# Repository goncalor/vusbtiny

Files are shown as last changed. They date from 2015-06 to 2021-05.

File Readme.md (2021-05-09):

# Introduction

VUSBtiny is a small in-system programmer (ISP) for Atmel AVR microcontrollers. It allows you to program microcontrollers on the go, without carrying a big programmer with you.

VUSBtiny is based on the [USBtinyISP](https://learn.adafruit.com/usbtinyisp). It uses an Atmel AVR microcontroller running [V-USB](https://www.obdev.at/products/vusb/index.html), which allows it to communicate with your computer via a USB port.

The programmer was not developed by me, but with this repository I added to it in some ways:

- edited the code so that it compiles with the most recent versions of `avr-gcc`
- designed a PCB for the project, in a way which should make it simple to be hand produced
- wrote this readme, which can help you make your own VUSBtiny.

You can find the original VUSBtiny page [here](https://web.archive.org/web/20180423215321/http://www.simpleavr.com/avr/vusbtiny) (or [here](https://simpleavr.github.io/old_projects/avr_vusbtiny/index.html)).

# License

VUSBtiny is licensed under [GNU GPL v2.0](http://choosealicense.com/licenses/gpl-2.0/). The license is in the file `LICENSE.txt`. The changes I made are released under the same license.

The V-USB driver is licensed under GNU GPL v2.0. If you intend to use V-USB commercially read [this page](https://www.obdev.at/products/vusb/license.html).

# Needed components

To assemble your own VUSBtiny you will need the following components:

- an Atmel AVR microcontroller [compatible with V-USB](https://www.obdev.at/products/vusb/index.html). I suggest ATtiny45 or ATtiny85
- one USB port (male and type A)
- two 68 Ω resistors
- one 1.5 kΩ resistor
- two 3.6 V Zener diodes
- a 10 μF capacitor (optional but recommended)
- a breadboard, perfboard or PCB to assemble the circuit.

# How to flash the AVR

The following instructions teach you how you can flash the Atmel AVR you chose to be the brain of your VUSBtiny. I will assume you are using ATtiny45 or ATtiny85. The instructions should be very similar even if you are using others.

## With an Arduino Uno

1. Choose a microcontroller compatible with V-USB. You can read about the required specs [here](https://www.obdev.at/products/vusb/). You need at least a 2 kB flash and 128 B of RAM. If you don't want to use an external oscillator your microcontroller must have a 16.5 MHz internal RC oscillator.
1. [Setup your Arduino as an ATtiny programmer](http://highlowtech.org/?p=1695)
1. Program Arduino Uno with the "ArduinoISP" sketch. This step is done without the capacitor between the RESET and GND pins of the Arduino. After you upload the "ArduinoISP" sketch connect the capacitor, as described in the link above
1. Adjust the following options in the `makefile`:
    - `MCU=attiny85`, for example
    - possibly adjust `PROGRAMMER_MCU` also. For ATtiny85/45 this is not needed
    - `AVRDUDE_PROGRAMMERID=avrisp`
    - `AVRDUDE_PORT=/dev/ttyACM0` or to whatever port the Arduino Uno is connected to. You check which port to use by running `dmesg` right after you connect your Arduino. The last lines in the output should mention some `tty` port
    - `BAUD=19200`. This value must match the one in the `Serial.begin()` in the "ArduinoISP" example
    - change the fuses if needed (`FUSE_L` and `FUSE_H`)
1. Do `make`. The source should compile successfully
1. Do `make install`
1. Set the fuses (if needed). On ATtiny85/45 we need to disable the reset pin which will be used as a normal I/O pin, which means you will not be able to program this microcontroller anymore using the Arduino Uno. If you need to reverse this step you need a HVSP (High Voltage Serial Programmer).
    - the fuses differ from device to device. The `makefile` is prepared for ATtiny85/45. If you have another MCU search for a fuse calculator that can aid you setting the correct fuses
    - when you're ready run `make fuse`

# How to use your new programmer

Your newly made programmer will be seen as a USBtinyISP programmer. That means the options you give to `avrdude` will be the same as if you had a true USBtinyISP connected. Example (flashing a simple blink code):

	avrdude -c usbtiny -p t85 -U flash:w:blinkC.hex

You may have to run with `sudo`, or set correct options in your system.

# Troubleshooting

1. Checking if your device was recognised

	Little after you connect the VUSBtiny to your computer if you run `dmesg` you should see something like this:

		[27548.612082] usb 4-1.5: new low-speed USB device number 105 using ehci-pci
		[27548.639576] usb 4-1.5: New USB device found, idVendor=1781, idProduct=0c9f
		[27548.639587] usb 4-1.5: New USB device strings: Mfr=0, Product=2, SerialNumber=0
		[27548.639592] usb 4-1.5: Product: USBtinyISP

	If instead you see only error messages this means the VUSBtiny was not correctly recognised, so it will not work. Try reconnecting.

2. When programming with VUSBtiny `avrdude` throws `Operation not permitted` error

		avrdude -c usbtiny -p t85 -U flash:w:blinkC.hex
	
		avrdude: error: usbtiny_transmit: error sending control message: Operation not permitted
		avrdude: initialization failed, rc=-1
		         Double check connections and try again, or use -F to override
		         this check.
	
		avrdude: error: usbtiny_transmit: error sending control message: Operation not permitted
		avrdude done.  Thank you.

	If you see `avrdude` throwing the previous error back atcha it is probably a permissions problem and you have two options:

	- run the command with `sudo` or
	- [write a udev rule](https://mightyohm.com/blog/2010/03/run-avrdude-without-root-privs-in-ubuntu/)

3. When programming with VUSBtiny `avrdude` throws `initialization failed, rc=-1` error

		avrdude -c usbtiny -p t85 -U flash:w:blinkC.hex 

		avrdude: initialization failed, rc=-1
			 Double check connections and try again, or use -F to override
			 this check.

		avrdude done.  Thank you.

	If you see this error you probably made a mistake when hooking up the programmer (VUSBtiny) to the target (whatever microcontroller you are programming). Recheck your connections against a 6-pin ISP header pinout and the MISO, MOSI, SCK, RST, VCC and GND pins of your microcontroller.

# Improvements

Some improvements that should be made to the PCB are:

- leave more space between the capacitor and the ISP headers. This way the capacitor can be bent to be made horizontal without difficulting access to the ISP header pins

- increase spacing between traces. This is meant to ease manual production and soldering of the board

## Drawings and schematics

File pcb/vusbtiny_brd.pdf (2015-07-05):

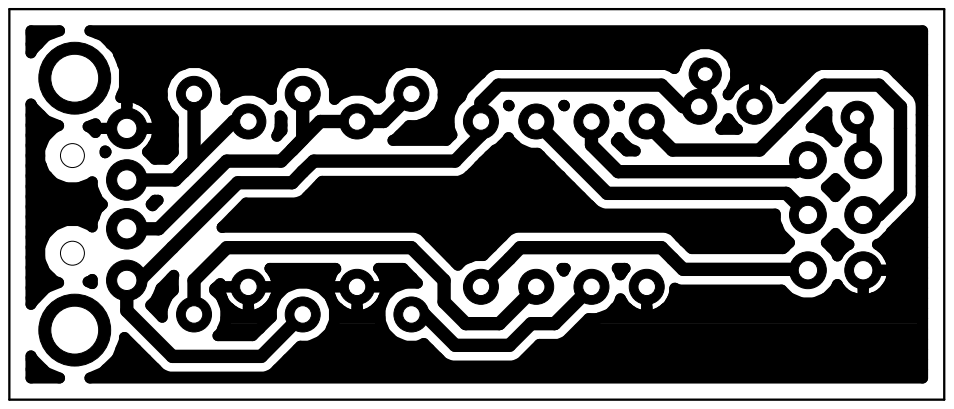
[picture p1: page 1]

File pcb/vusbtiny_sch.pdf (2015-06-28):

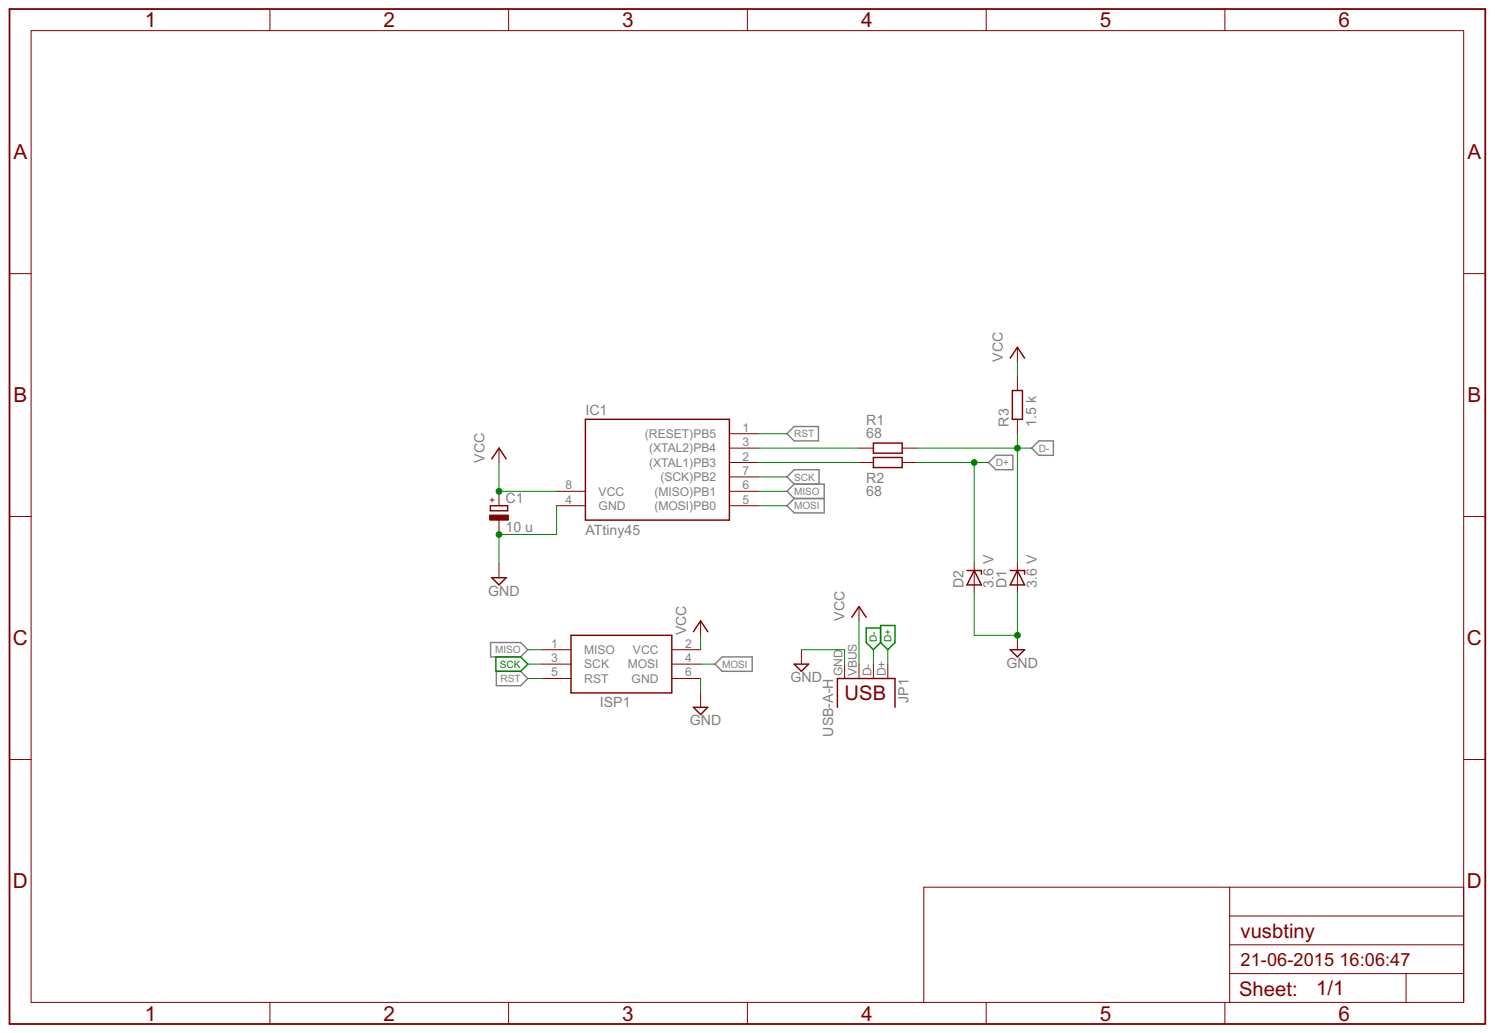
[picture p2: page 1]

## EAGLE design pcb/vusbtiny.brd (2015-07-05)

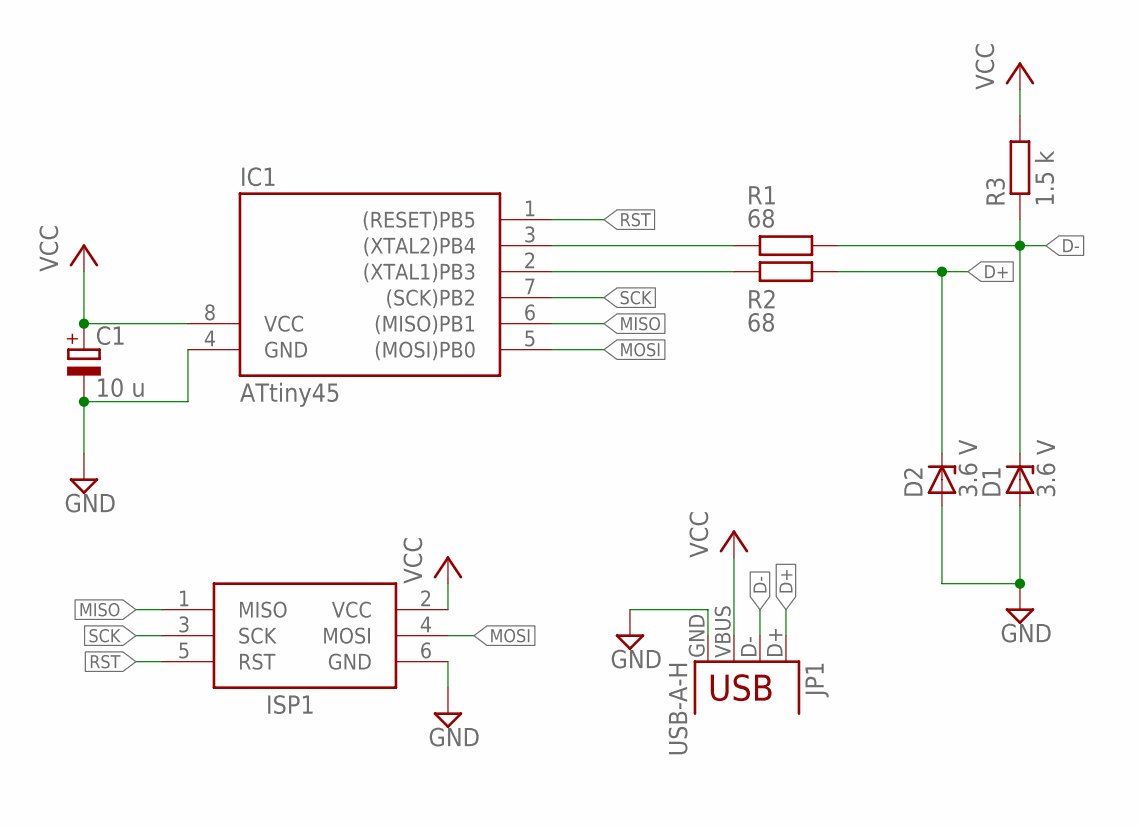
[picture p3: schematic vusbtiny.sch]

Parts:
C1: 10 u; E2,5-5
D1, D2: 3.6 V; DO34Z7
IC1: ATtiny45; DIL08
ISP1: AVRISP-6; AVRISP
JP1: USB-A-H
R1, R2: 68; 0207/10
R3: 1.5 k; 0207/10

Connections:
D+: D2.C, JP1.D+, R2.2
D-: D1.C, JP1.D-, R1.2, R3.1
GND: C1.-, D1.A, D2.A, IC1.4 (GND), ISP1.6 (GND), JP1.GND
MISO: IC1.6 ((MISO)PB1), ISP1.1 (MISO)
MOSI: IC1.5 ((MOSI)PB0), ISP1.4 (MOSI)
unnamed: IC1.3 ((XTAL2)PB4), R1.1
unnamed: IC1.2 ((XTAL1)PB3), R2.1
RST: IC1.1 ((RESET)PB5), ISP1.5 (RST)
SCK: IC1.7 ((SCK)PB2), ISP1.3 (SCK)
VCC: C1.+, IC1.8 (VCC), ISP1.2 (VCC), JP1.VBUS, R3.2

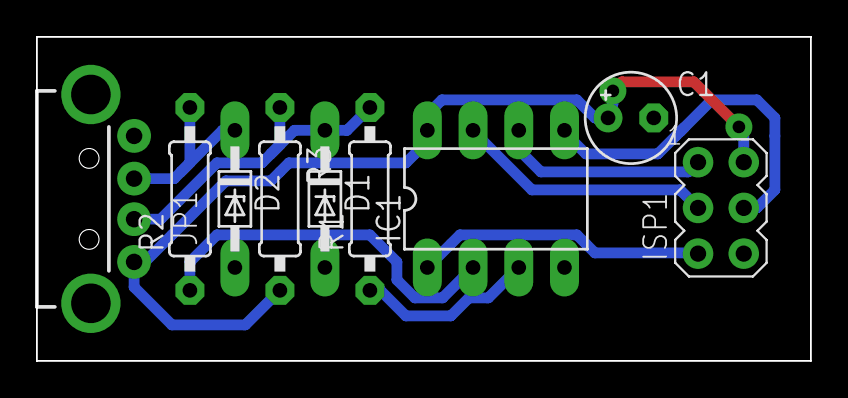
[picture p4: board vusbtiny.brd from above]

Board: 2 copper layers, 43.0 x 18.0 mm, 9 parts (0 on the bottom side), 10 nets.

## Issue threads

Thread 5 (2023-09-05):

Default config for ATtiny85 incompatible with existing ATtiny85 USB boards

Smity, 2023-09-05:
The provided schematic and usbconfig.h file has the D+/- bits swapped relative to the ATtiny85 USB boards you can buy online. As far as I can tell, all of those boards are either copies or derivatives of Digispark's design, which has D+ on PB4 and D- on PB3. I'm mainly opening this issue so others don't have to go through the same hours of head-scratching I did, because I think this is a fantastic project and, once I fixed that, everything worked perfectly.

vaclavhanzl, 2023-11-18:
Also note that makefile is missing some dependencies (I'll create a separate issue for that) so if you try compile, then swap pins in config and then recompile, you can still face troubles. So for the record and to save some people yet more hours or days, this way currently works:
```
git clone git@github.com:goncalor/vusbtiny.git
cd vusbtiny
# Before 'make', first edit usbconfig.h - the pin swap is already prepared there, just comment/uncomment.
# (There is nothing to change about interrupts, as you may wonder reading the comments.)
make
# Now you have the right vusbtiny.hex
```

vaclavhanzl, 2023-11-29:
Fixed makefile and swapped USB data pins as needed for the tiny Digispark-like HW-260 boards can be found in [my HW-260 branch](https://github.com/vaclavhanzl/vusbtiny/tree/HW-260).

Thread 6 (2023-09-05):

make clean removes .s (assembly) files

Smity, 2023-09-05:
...after which, the compiler can't find the necessary assembly files to build the program (because they've been deleted).

To fix, I had to remove `$(DUMPTRG)` from line 312, and `(REMOVE) $(GENASMFILES)` from line 324.

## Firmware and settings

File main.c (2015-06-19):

/* Name: main.c
  
  created by chris chung, 2010 April

  based on the works found in

  v-usb framework http://www.obdev.at/vusb/
	 Project: Thermostat based on AVR USB driver
	 Author: Christian Starkjohann
    
  usbtiny isp http://www.xs4all.nl/~dicks/avr/usbtiny/
  	Dick Streefland
  
  please observe licensing term from the above two projects

	Copyright (C) 2010  chris chung

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

  **** fuse setting, 
  **** this will blow reset fuse, u will need to use HV programmer to recover if u mess up
  avrdude -c usbtiny -p t45 -V -U lfuse:w:0xe1:m -U hfuse:w:0x5d:m -U efuse:w:0xff:m 
 */

#include <avr/io.h>
#include <avr/wdt.h>
#include <avr/eeprom.h>
#include <avr/interrupt.h>
#include <avr/pgmspace.h>
#include <util/delay.h>
#include <stdlib.h>

#include "usbdrv.h"
#include "oddebug.h"

enum
{
	// Generic requests
	USBTINY_ECHO,		// echo test
	USBTINY_READ,		// read byte (wIndex:address)
	USBTINY_WRITE,		// write byte (wIndex:address, wValue:value)
	USBTINY_CLR,		// clear bit (wIndex:address, wValue:bitno)
	USBTINY_SET,		// set bit (wIndex:address, wValue:bitno)
	// Programming requests
	USBTINY_POWERUP,	// apply power (wValue:SCK-period, wIndex:RESET)
	USBTINY_POWERDOWN,	// remove power from chip
	USBTINY_SPI,		// issue SPI command (wValue:c1c0, wIndex:c3c2)
	USBTINY_POLL_BYTES,	// set poll bytes for write (wValue:p1p2)
	USBTINY_FLASH_READ,	// read flash (wIndex:address)
	USBTINY_FLASH_WRITE,	// write flash (wIndex:address, wValue:timeout)
	USBTINY_EEPROM_READ,	// read eeprom (wIndex:address)
	USBTINY_EEPROM_WRITE,	// write eeprom (wIndex:address, wValue:timeout)
};

#define	PORT	PORTB
#define	DDR		DDRB
#define	PIN		PINB

//
// to reduce pin count so that this can fit in a 8 pin tiny
// . no power nor ground pins to target, they are to be connected always
// . no reset control pin to target, target reset always grounded
//   * this had caused problem and there are two solutions
//     1. provide a toggle switch to off-on-off target reset to ground
//     2. introduce reset control and use reset pin as io
//
#define	POWER_MASK	0x00
#define	GND_MASK	0x00

#define	RESET_MASK	(1 << 5)
#define	SCK_MASK	(1 << 2)
#define	MISO_MASK	(1 << 1)
#define	MOSI_MASK	(1 << 0)

// ----------------------------------------------------------------------
// Programmer input pins:
//	MISO	PD3	(ACK)
// ----------------------------------------------------------------------

// ----------------------------------------------------------------------
// Local data
// ----------------------------------------------------------------------
static	uchar		sck_period=50;	// SCK period in microseconds (1..250)
static	uchar		poll1;		// first poll byte for write
static	uchar		poll2;		// second poll byte for write
static	unsigned		address;	// read/write address
static	unsigned		timeout;	// write timeout in usec
static	uchar		cmd0;		// current read/write command byte
static	uchar		cmd[4];		// SPI command buffer
static	uchar		res[4];		// SPI result buffer

// ----------------------------------------------------------------------
// Delay exactly <sck_period> times 0.5 microseconds (6 cycles).
// ----------------------------------------------------------------------
__attribute__((always_inline))
static inline void delay ( void )
{
	asm volatile(
		"	mov	__tmp_reg__,%0	\n"
		"0:	rjmp	1f		\n"
		"1:	nop			\n"
		"2:	nop			\n"
		"3:	nop			\n"
		"	dec	__tmp_reg__	\n"
		"	brne	0b		\n"
		: : "r" (sck_period) );
}

// ----------------------------------------------------------------------
// Issue one SPI command.
// ----------------------------------------------------------------------
static	void	spi ( uchar* cmd, uchar* res )
{
	uchar	i;
	uchar	c;
	uchar	r;
	uchar	mask;

	for	( i = 0; i < 4; i++ )
	{
		c = *cmd++;
		r = 0;
		for	( mask = 0x80; mask; mask >>= 1 )
		{
			if	( c & mask )
			{
				PORT |= MOSI_MASK;
			}
			delay();
			PORT |= SCK_MASK;
			delay();
			r <<= 1;
			if	( PIN & MISO_MASK )
			{
				r++;
			}
			PORT &= ~MOSI_MASK;
			PORT &= ~SCK_MASK;
		}
		*res++ = r;
	}
}

// ----------------------------------------------------------------------
// Create and issue a read or write SPI command.
// ----------------------------------------------------------------------
static	void	spi_rw ( void )
{
	unsigned	a;

	a = address++;
	if	( cmd0 & 0x80 )
	{	// eeprom
		a <<= 1;
	}
	cmd[0] = cmd0;
	if	( a & 1 )
	{
		cmd[0] |= 0x08;
	}
	cmd[1] = a >> 9;
	cmd[2] = a >> 1;
	spi( cmd, res );
}

// ----------------------------------------------------------------------
// Handle an IN packet.
// ----------------------------------------------------------------------
uchar usbFunctionRead(uchar *data, uchar len)
{
	uchar	i;

	for	( i = 0; i < len; i++ )
	{
		spi_rw();
		data[i] = res[3];
	}
	return len;
}

// ----------------------------------------------------------------------
// Handle an OUT packet.
// ----------------------------------------------------------------------
uchar usbFunctionWrite(uchar *data, uchar len)
{
	uchar	i;
	unsigned	usec;
	uchar	r;
	//uchar	last = (len != 8);

	for	( i = 0; i < len; i++ )
	{
		cmd[3] = data[i];
		spi_rw();
		cmd[0] ^= 0x60;	// turn write into read
		//
		for	( usec = 0; usec < timeout; usec += 32 * sck_period )
		{	// when timeout > 0, poll until byte is written
			spi( cmd, res );
			r = res[3];
			if	( r == cmd[3] && r != poll1 && r != poll2 )
			{
				break;
			}
		}
		//
	}
	//return last;
	return 1;
}

/* ------------------------------------------------------------------------- */
/* ------------------------ interface to USB driver ------------------------ */
/* ------------------------------------------------------------------------- */

uchar	usbFunctionSetup(uchar data[8])
{
// ----------------------------------------------------------------------
// Handle a non-standard SETUP packet.
// ----------------------------------------------------------------------
	uchar	bit;
	uchar	mask;
	uchar*	addr;
	uchar	req;

	// Generic requests
	req = data[1];
	if	( req == USBTINY_ECHO )
	{
		usbMsgPtr = data;
		return 8;
	}
	addr = (uchar*) (int) data[4];
	if	( req == USBTINY_READ )
	{
		data[0] = *addr;
		usbMsgPtr = data;
		return 1;
	}
	if	( req == USBTINY_WRITE )
	{
		*addr = data[2];
		return 0;
	}
	bit = data[2] & 7;
	mask = 1 << bit;
	if	( req == USBTINY_CLR )
	{
		*addr &= ~ mask;
		return 0;
	}
	if	( req == USBTINY_SET )
	{
		*addr |= mask;
		return 0;
	}

	// Programming requests
	if	( req == USBTINY_POWERUP )
	{
		sck_period = data[2];
		mask = POWER_MASK;
		if	( data[4] )
		{
			mask |= RESET_MASK;
		}
		DDR  &= ~MISO_MASK;
		DDR  |= (RESET_MASK|SCK_MASK|MOSI_MASK);
		PORT &= ~(RESET_MASK|SCK_MASK|MOSI_MASK|MISO_MASK);
		return 0;
	}
	if	( req == USBTINY_POWERDOWN )
	{
		//PORT |= RESET_MASK;
		//DDR  &= ~(SCK_MASK|MOSI_MASK);
		DDRB  = RESET_MASK;
		PORTB = RESET_MASK;
		return 0;
	}
	/* have to remove the following check as we strip a lot of io
	if	( ! PORT )
	{
		return 0;
	}
	*/
	if	( req == USBTINY_SPI )
	{
		spi( data + 2, data + 0 );
		usbMsgPtr = data;
		return 4;
	}
	if	( req == USBTINY_POLL_BYTES )
	{
		poll1 = data[2];
		poll2 = data[3];
		return 0;
	}
	address = * (unsigned*) & data[4];
	if	( req == USBTINY_FLASH_READ )
	{
		cmd0 = 0x20;
		return 0xff;	// usb_in() will be called to get the data
	}
	if	( req == USBTINY_EEPROM_READ )
	{
		cmd0 = 0xa0;
		return 0xff;	// usb_in() will be called to get the data
	}
	timeout = * (unsigned*) & data[2];
	if	( req == USBTINY_FLASH_WRITE )
	{
		cmd0 = 0x40;
		return 0xff;	// data will be received by usb_out()
	}
	if	( req == USBTINY_EEPROM_WRITE )
	{
		cmd0 = 0xc0;
		return 0xff;	// data will be received by usb_out()
	}
	return 0;
}


/* ------------------------------------------------------------------------- */
/* ------------------------ Oscillator Calibration ------------------------- */
/* ------------------------------------------------------------------------- */

/* Calibrate the RC oscillator to 8.25 MHz. The core clock of 16.5 MHz is
 * derived from the 66 MHz peripheral clock by dividing. Our timing reference
 * is the Start Of Frame signal (a single SE0 bit) available immediately after
 * a USB RESET. We first do a binary search for the OSCCAL value and then
 * optimize this value with a neighboorhod search.
 * This algorithm may also be used to calibrate the RC oscillator directly to
 * 12 MHz (no PLL involved, can therefore be used on almost ALL AVRs), but this
 * is wide outside the spec for the OSCCAL value and the required precision for
 * the 12 MHz clock! Use the RC oscillator calibrated to 12 MHz for
 * experimental purposes only!
 */
static void calibrateOscillator(void)
{
uchar       step = 128;
uchar       trialValue = 0, optimumValue;
int         x, optimumDev, targetValue = (unsigned)(1499 * (double)F_CPU / 10.5e6 + 0.5);

    /* do a binary search: */
    do{
        OSCCAL = trialValue + step;
        x = usbMeasureFrameLength();    /* proportional to current real frequency */
        if(x < targetValue)             /* frequency still too low */
            trialValue += step;
        step >>= 1;
    }while(step > 0);
    /* We have a precision of +/- 1 for optimum OSCCAL here */
    /* now do a neighborhood search for optimum value */
    optimumValue = trialValue;
    optimumDev = x; /* this is certainly far away from optimum */
    for(OSCCAL = trialValue - 1; OSCCAL <= trialValue + 1; OSCCAL++){
        x = usbMeasureFrameLength() - targetValue;
        if(x < 0)
            x = -x;
        if(x < optimumDev){
            optimumDev = x;
            optimumValue = OSCCAL;
        }
    }
    OSCCAL = optimumValue;
}
/*
Note: This calibration algorithm may try OSCCAL values of up to 192 even if
the optimum value is far below 192. It may therefore exceed the allowed clock
frequency of the CPU in low voltage designs!
You may replace this search algorithm with any other algorithm you like if
you have additional constraints such as a maximum CPU clock.
For version 5.x RC oscillators (those with a split range of 2x128 steps, e.g.
ATTiny25, ATTiny45, ATTiny85), it may be useful to search for the optimum in
both regions.
*/

void    usbEventResetReady(void)
{
    calibrateOscillator();
    eeprom_write_byte(0, OSCCAL);   /* store the calibrated value in EEPROM */
}

/* ------------------------------------------------------------------------- */
/* --------------------------------- main ---------------------------------- */
/* ------------------------------------------------------------------------- */

int main(void) {
	uchar   i;
	uchar   calibrationValue;

	//DDRB  = (RESET_MASK|SCK_MASK|MOSI_MASK);
	DDRB  = RESET_MASK;
	PORTB = RESET_MASK;
	/*
	_delay_ms(25);
	uchar pgm[] = { 0xac, 0x53, 0x00, 0x00, 0x00, 0x00, 0x00, 0x00, };
	spi(pgm, pgm+4);
	*/
    calibrationValue = eeprom_read_byte(0); /* calibration value from last time */
    if(calibrationValue != 0xff){
        OSCCAL = calibrationValue;
    }
    odDebugInit();
    usbDeviceDisconnect();
    for(i=0;i<20;i++){  /* 300 ms disconnect */
        _delay_ms(15);
    }
    usbDeviceConnect();

    wdt_enable(WDTO_1S);

    usbInit();
    sei();
    for(;;){    /* main event loop */
        wdt_reset();
        usbPoll();
    }
    return 0;
}

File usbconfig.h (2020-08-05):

/* Name: usbconfig.h
 * Project: AVR USB driver
 * Author: Christian Starkjohann
 * Creation Date: 2007-06-23
 * Tabsize: 4
 * Copyright: (c) 2007 by OBJECTIVE DEVELOPMENT Software GmbH
 * License: GNU GPL v2 (see License.txt) or proprietary (CommercialLicense.txt)
 * This Revision: $Id: usbconfig.h 537 2008-02-28 21:13:01Z cs $
 */

#ifndef __usbconfig_h_included__
#define __usbconfig_h_included__

/* ---------------------------- Hardware Config ---------------------------- */

#define USB_CFG_IOPORTNAME      B
/* This is the port where the USB bus is connected. When you configure it to
 * "B", the registers PORTB, PINB and DDRB will be used.
 */
#define USB_CFG_DMINUS_BIT      4
//#define USB_CFG_DMINUS_BIT      3
/* This is the bit number in USB_CFG_IOPORT where the USB D- line is connected.
 * This may be any bit in the port.
 */
#define USB_CFG_DPLUS_BIT       3
//#define USB_CFG_DPLUS_BIT       4
/* This is the bit number in USB_CFG_IOPORT where the USB D+ line is connected.
 * This may be any bit in the port. Please note that D+ must also be connected
 * to interrupt pin INT0! (or you need to change some defines on the bottom
 * of this file.)
 */
#define USB_CFG_CLOCK_KHZ       (F_CPU/1000)
/* Clock rate of the AVR in MHz. Legal values are 12000, 16000 or 16500.
 * The 16.5 MHz version of the code requires no crystal, it tolerates +/- 1%
 * deviation from the nominal frequency. All other rates require a precision
 * of 2000 ppm and thus a crystal!
 * Default if not specified: 12 MHz
 */

/* ----------------------- Optional Hardware Config ------------------------ */

/* #define USB_CFG_PULLUP_IOPORTNAME   D */
/* If you connect the 1.5k pullup resistor from D- to a port pin instead of
 * V+, you can connect and disconnect the device from firmware by calling
 * the macros usbDeviceConnect() and usbDeviceDisconnect() (see usbdrv.h).
 * This constant defines the port on which the pullup resistor is connected.
 */
/* #define USB_CFG_PULLUP_BIT          4 */
/* This constant defines the bit number in USB_CFG_PULLUP_IOPORT (defined
 * above) where the 1.5k pullup resistor is connected. See description
 * above for details.
 */

/* --------------------------- Functional Range ---------------------------- */

#define USB_CFG_HAVE_INTRIN_ENDPOINT    1
/* Define this to 1 if you want to compile a version with two endpoints: The
 * default control endpoint 0 and an interrupt-in endpoint 1.
 */
#define USB_CFG_HAVE_INTRIN_ENDPOINT3   0
/* Define this to 1 if you want to compile a version with three endpoints: The
 * default control endpoint 0, an interrupt-in endpoint 1 and an interrupt-in
 * endpoint 3. You must also enable endpoint 1 above.
 */
#define USB_CFG_IMPLEMENT_HALT          0
/* Define this to 1 if you also want to implement the ENDPOINT_HALT feature
 * for endpoint 1 (interrupt endpoint). Although you may not need this feature,
 * it is required by the standard. We have made it a config option because it
 * bloats the code considerably.
 */
#define USB_CFG_INTR_POLL_INTERVAL      10
/* If you compile a version with endpoint 1 (interrupt-in), this is the poll
 * interval. The value is in milliseconds and must not be less than 10 ms for
 * low speed devices.
 */
#define USB_CFG_IS_SELF_POWERED         0
/* Define this to 1 if the device has its own power supply. Set it to 0 if the
 * device is powered from the USB bus.
 */
#define USB_CFG_MAX_BUS_POWER           200
/* Set this variable to the maximum USB bus power consumption of your device.
 * The value is in milliamperes. [It will be divided by two since USB
 * communicates power requirements in units of 2 mA.]
 */
#define USB_CFG_IMPLEMENT_FN_WRITE      1
/* Set this to 1 if you want usbFunctionWrite() to be called for control-out
 * transfers. Set it to 0 if you don't need it and want to save a couple of
 * bytes.
 */
#define USB_CFG_IMPLEMENT_FN_READ       1
/* Set this to 1 if you need to send control replies which are generated
 * "on the fly" when usbFunctionRead() is called. If you only want to send
 * data from a static buffer, set it to 0 and return the data from
 * usbFunctionSetup(). This saves a couple of bytes.
 */
#define USB_CFG_IMPLEMENT_FN_WRITEOUT   0
/* Define this to 1 if you want to use interrupt-out (or bulk out) endpoint 1.
 * You must implement the function usbFunctionWriteOut() which receives all
 * interrupt/bulk data sent to endpoint 1.
 */
#define USB_CFG_HAVE_FLOWCONTROL        0
/* Define this to 1 if you want flowcontrol over USB data. See the definition
 * of the macros usbDisableAllRequests() and usbEnableAllRequests() in
 * usbdrv.h.
 */
#ifndef __ASSEMBLER__
extern void usbEventResetReady(void);
#endif
#define USB_RESET_HOOK(isReset)             if(!isReset){usbEventResetReady();}
/* This macro is a hook if you need to know when an USB RESET occurs. It has
 * one parameter which distinguishes between the start of RESET state and its
 * end.
 */
#define USB_CFG_HAVE_MEASURE_FRAME_LENGTH   1
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

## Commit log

2015-06-20 Updated the Readme. Corrected the USB device name.
    [usbconfig.h]
2015-06-28 Added hardware files. Placed but still unrouted.
    [vusbtiny.brd, vusbtiny.sch]
2015-07-04 Reposition components to ease routing. Added DRC.
    [vusbtiny.brd]
2015-07-05 Finished routing. Copper pour should be improved.
    [vusbtiny.brd, vusbtiny.sch]
2015-07-05 Finished routing. Wrote script to make board's pdf
    [vusbtiny.brd, vusbtiny.sch]
2015-08-16 Edited the Readme. Added a blinking LED example.
2020-02-07 Update usbconfig.h
    Added commented lines for inverted D- / D+ lines devices
    [usbconfig.h]

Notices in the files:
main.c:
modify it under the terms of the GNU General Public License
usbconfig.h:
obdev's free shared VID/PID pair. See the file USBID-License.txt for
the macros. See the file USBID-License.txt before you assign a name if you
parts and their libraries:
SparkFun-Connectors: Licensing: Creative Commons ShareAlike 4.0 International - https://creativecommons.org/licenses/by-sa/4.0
